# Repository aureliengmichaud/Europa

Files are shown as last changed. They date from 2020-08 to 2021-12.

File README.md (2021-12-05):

Europa Logo


 

A simple and practical 4x4 mechanical keypad.

 PCB Front Render

## Features

 * Simple and usable layout.
 * Driven by Arduino Pro Micro.
 * Cheap if using FR-4 plates (PCB material).
 * Awesome looking sandwich case.
 * No LEDs and no underglow.
 * Not another swiss cheese PCB.
 * Fully open source.
 * Powered by [QMK Firmware](https://github.com/qmk/qmk_firmware).

## PCB

### Front

 PCB Front

### Back

 PCB Back

### Files

 Grab the zip containing the gerbers files needed for manufacturing [here](https://github.com/aureliengmichaud/Europa/blob/master/Europa-PCB-Gerbers-Rev1.zip).

## Plates

### Switch Plate

 Switch Plate

### Bottom Plate

 Bottom Plate

### Files

 Grab the files needed to get the plates made or modified in KiCad [here](https://github.com/aureliengmichaud/Europa/tree/master/Plates). DXF and SVG files are included, depending on the manufacturer's needs. If you choose to get them made in PCB material (FR-4), you'll find the gerbers for the switch plate [here](https://github.com/aureliengmichaud/Europa/blob/master/Europa-Switch-Plate-Gerbers-Rev1.zip) and the bottom plate [here](https://github.com/aureliengmichaud/Europa/blob/master/Europa-Bottom-Plate-Gerbers-Rev1.zip).

## Parts List

 Part  |  Quantity
 :----  |  :--------:
 [Europa PCB](https://github.com/aureliengmichaud/Europa/blob/master/Europa-PCB-Gerbers-Rev1.zip)  |  1
 [1N4148 Diodes](https://candykeys.com/product/fairchild-semiconductor-diode-1n4148-pack-of-100)  |  16
 [Pro Micro Microcontroller](https://candykeys.com/product/pro-micro-5v-16mhz)  |  1
 [Cherry MX Switches  (or compatible)](https://candykeys.com/category:switches/brand:cherry)  |  16
 [Europa Switch Plate](https://github.com/aureliengmichaud/Europa/tree/master/Plates)  |  1
 [Europa Bottom Plate](https://github.com/aureliengmichaud/Europa/tree/master/Plates)  |  1
 [M3x8 Screws](https://www.ebay.fr/sch/i.html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)  |  16
 [M3x14 Standoffs](https://www.ebay.fr/sch/i.html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)  |  8
 [Micro-USB Cable](https://voltacharger.com/products/volta-2-0)  | 1
 [Keycaps](https://www.aliexpress.com/wholesale?catId=0&initiative_id=SB_20200426114303&SearchText=keycaps)  |  16

## Firmware

 The keyboard is powered by [QMK Firmware](https://github.com/qmk/qmk_firmware). You can find the firmware for the Europa [here](https://github.com/aureliengmichaud/Europa/tree/master/Firmware/aureliengmichaud/europa).

 Add the `aureliengmichaud` folder to your own fork of QMK to flash it to your keyboard.

 If you're new to QMK, please take the time to learn all the ins and outs and familiarize yourself with it by reading the [official documentation](https://docs.qmk.fm/#/).

## License

 Released under [MIT License](https://github.com/aureliengmichaud/Europa/blob/master/LICENSE).

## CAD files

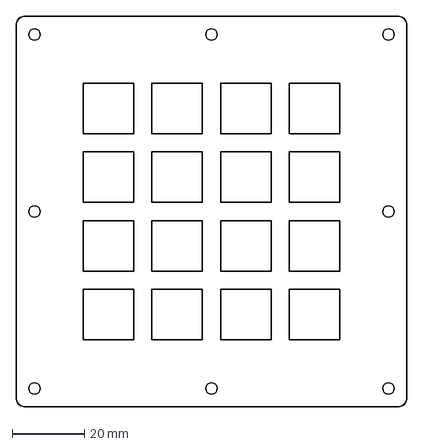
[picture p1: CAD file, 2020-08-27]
Plates/DXF/europa-switch-plate-ai.dxf
108.0 x 108.0 mm

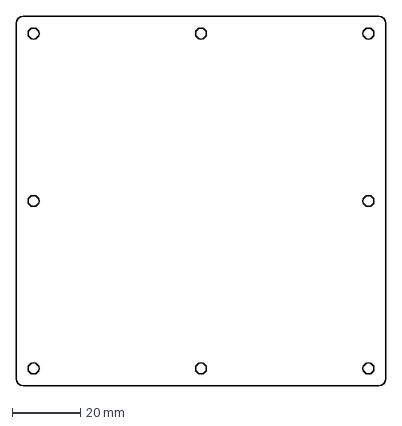
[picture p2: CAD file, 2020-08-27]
Plates/DXF/europa-bottom-plate-ai.dxf
108.0 x 108.0 mm

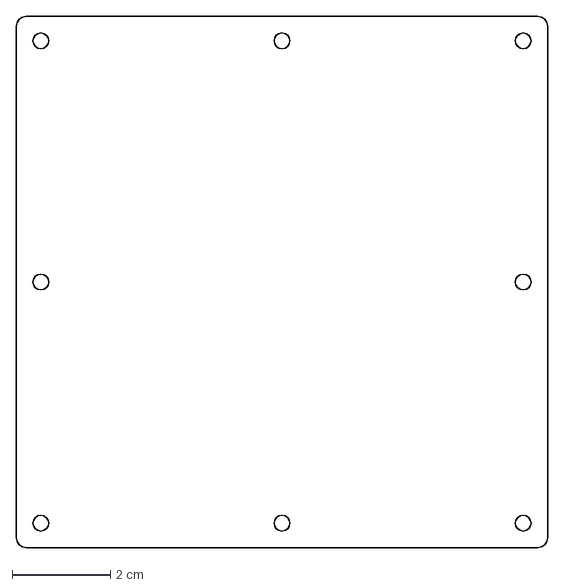
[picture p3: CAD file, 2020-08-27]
Plates/DXF/europa-bottom-plate-f360.dxf
10.8 x 10.8 cm

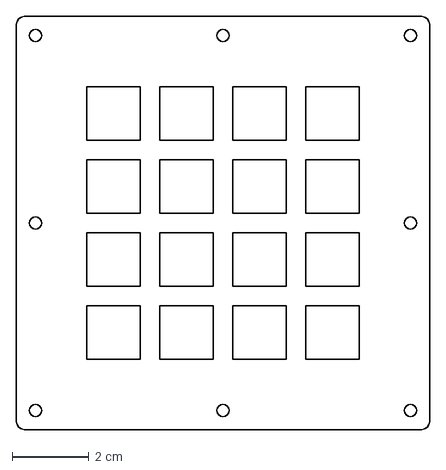
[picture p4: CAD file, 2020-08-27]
Plates/DXF/europa-switch-plate-f360.dxf
10.8 x 10.8 cm

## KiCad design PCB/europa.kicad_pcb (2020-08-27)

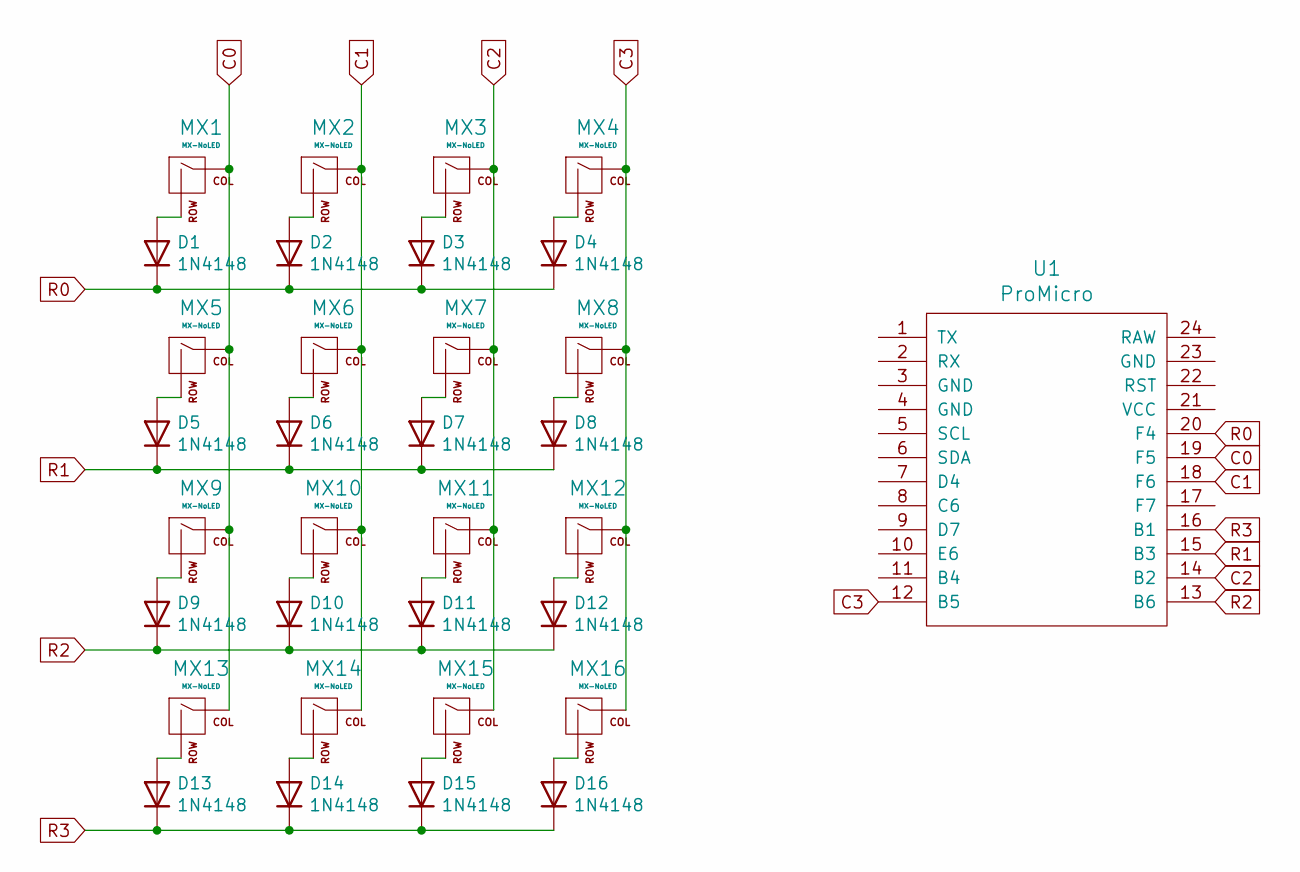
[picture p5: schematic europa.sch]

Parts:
D1, D2, D3, D4, D5, D6, D7, D8, D9, D10, D11, D12, D13, D14, D15, D16: 1N4148; D_DO-35_SOD27_P7.62mm_Horizontal
MX1, MX2, MX3, MX4, MX5, MX6, MX7, MX8, MX9, MX10, MX11, MX12, MX13, MX14, MX15, MX16: MX-NoLED; MXOnly-1U-NoLED
U1: ProMicro

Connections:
C0: MX1.1 (COL), MX5.1 (COL), MX9.1 (COL), MX13.1 (COL), U1.19 (F5)
C1: MX2.1 (COL), MX6.1 (COL), MX10.1 (COL), MX14.1 (COL), U1.18 (F6)
C2: MX3.1 (COL), MX7.1 (COL), MX11.1 (COL), MX15.1 (COL), U1.14 (B2)
C3: MX4.1 (COL), MX8.1 (COL), MX12.1 (COL), MX16.1 (COL), U1.12 (B5)
unnamed: D1.2 (A), MX1.2 (ROW)
unnamed: D2.2 (A), MX2.2 (ROW)
unnamed: D3.2 (A), MX3.2 (ROW)
unnamed: D4.2 (A), MX4.2 (ROW)
unnamed: D5.2 (A), MX5.2 (ROW)
unnamed: D6.2 (A), MX6.2 (ROW)
unnamed: D7.2 (A), MX7.2 (ROW)
unnamed: D8.2 (A), MX8.2 (ROW)
unnamed: D9.2 (A), MX9.2 (ROW)
unnamed: D10.2 (A), MX10.2 (ROW)
unnamed: D11.2 (A), MX11.2 (ROW)
unnamed: D12.2 (A), MX12.2 (ROW)
unnamed: D13.2 (A), MX13.2 (ROW)
unnamed: D14.2 (A), MX14.2 (ROW)
unnamed: D15.2 (A), MX15.2 (ROW)
unnamed: D16.2 (A), MX16.2 (ROW)
R0: D1.1 (K), D2.1 (K), D3.1 (K), D4.1 (K), U1.20 (F4)
R1: D5.1 (K), D6.1 (K), D7.1 (K), D8.1 (K), U1.15 (B3)
R2: D9.1 (K), D10.1 (K), D11.1 (K), D12.1 (K), U1.13 (B6)
R3: D13.1 (K), D14.1 (K), D15.1 (K), D16.1 (K), U1.16 (B1)

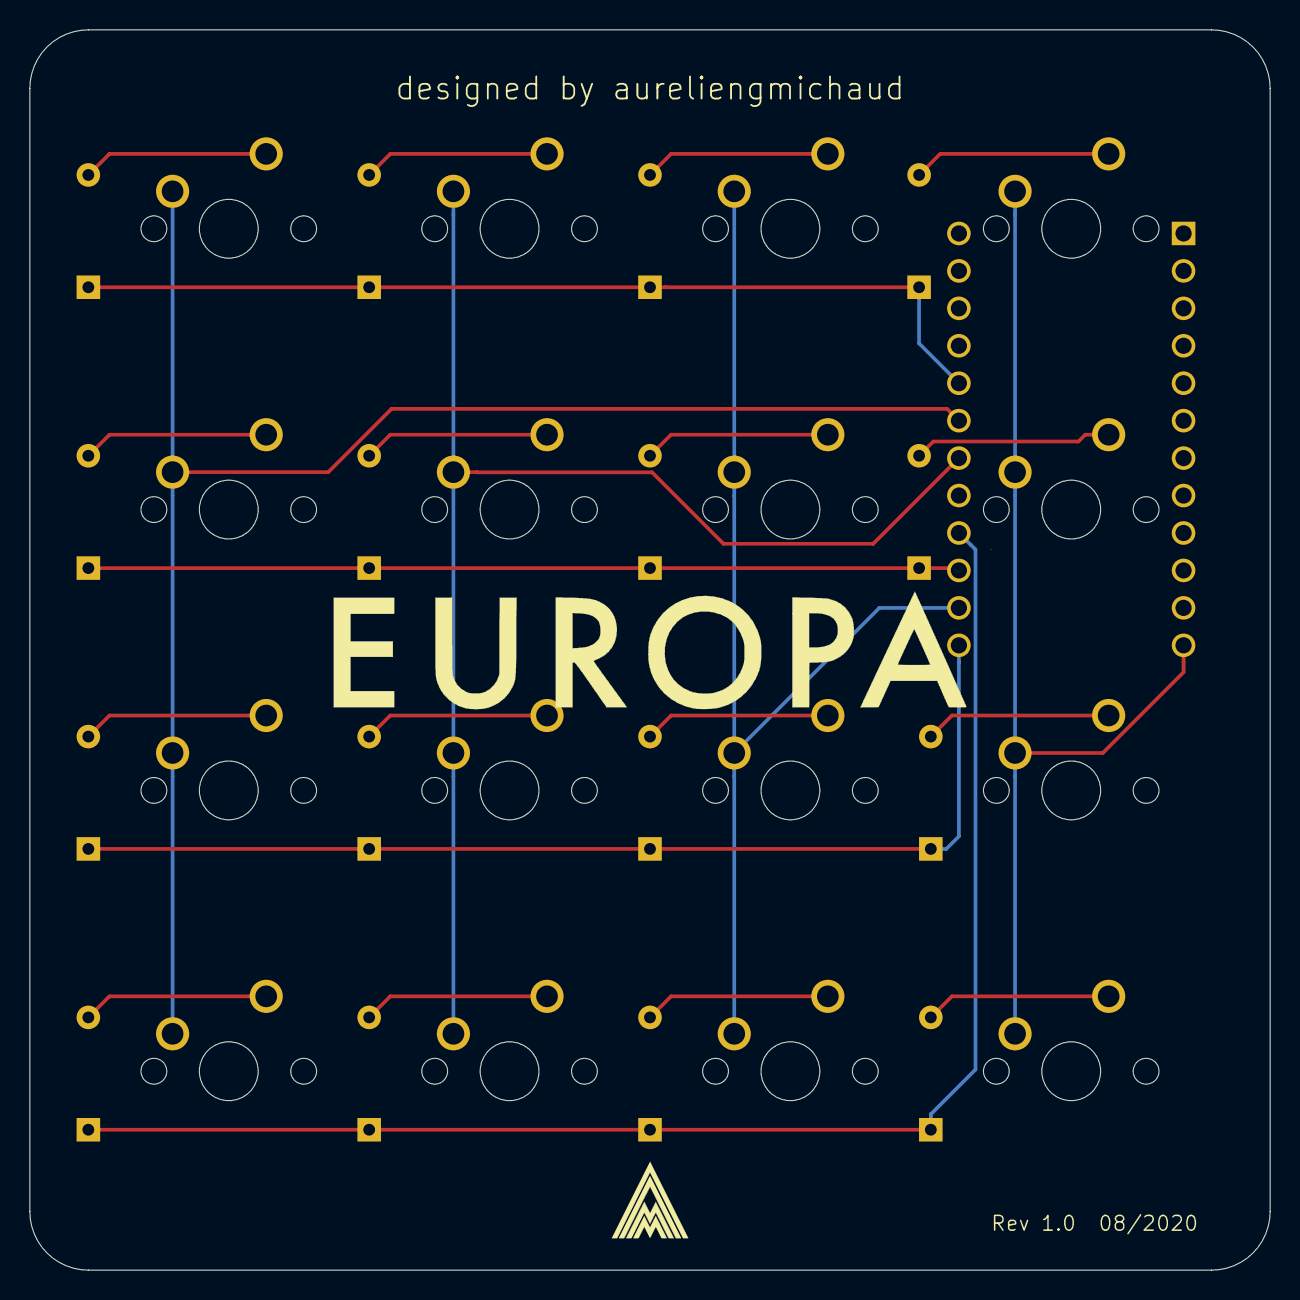
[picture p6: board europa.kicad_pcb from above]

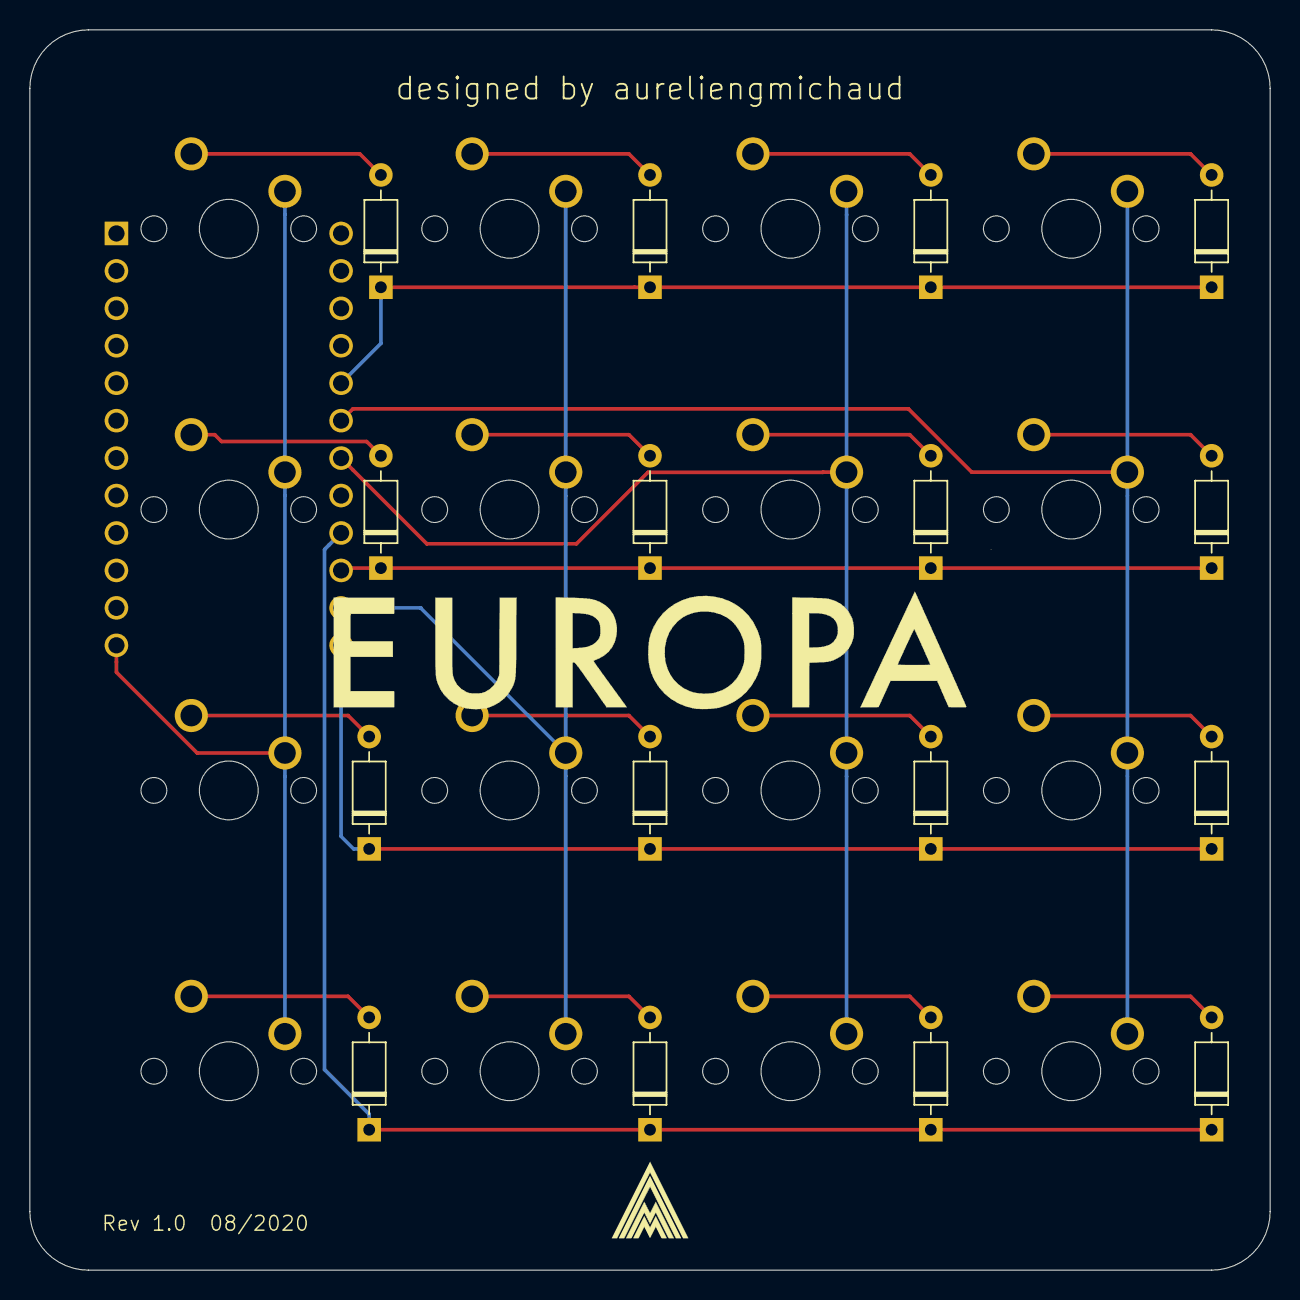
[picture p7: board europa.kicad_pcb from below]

Board: 2 copper layers, 84.1 x 84.1 mm, 33 parts (17 on the bottom side), 24 nets.

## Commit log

2020-08-27 Add PCB & Plates
    [europa-B_Cu.gbl, europa-B_Mask.gbs, europa-B_SilkS.gbo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]
2020-08-27 Add PCB / Plates
2020-08-27 Update PCB Gerbers
2020-08-27 Update Plates
    [europa-bottom-plate-B_Cu.gbl, europa-bottom-plate-B_Mask.gbs, europa-bottom-plate-B_SilkS.gbo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]
2020-09-14 Update Europa
    [europa-B_Cu.gbl, europa-B_Mask.gbs, europa-B_SilkS.gbo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]
